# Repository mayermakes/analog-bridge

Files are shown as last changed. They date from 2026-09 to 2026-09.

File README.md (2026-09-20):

# Analog Bridge

A modular, open hardware 16-channel measurement and logic-monitoring platform built around an ATtiny3226 and four ADS1115 ADCs. The bridge exposes a line-oriented SCPI interface over Ethernet and USB serial, making it useful for automated test fixtures, digital logic observation, and lightweight data acquisition.

> **Status:** Work in progress. The hardware, firmware, and host tools are under active development.

## Features

- 16 single-ended analog inputs per device
- 3.3 V logic-level classification in the included monitor application
- Four ADS1115 converters on a shared I²C bus
- ATtiny3226-based firmware
- Ethernet connectivity through an ENC28J60
- USB-UART access at 115200 8N1
- SCPI commands for identification, channel configuration, status, and measurements
- Python web dashboards for live channel monitoring and oscilloscope-style plotting
- KiCad PCB and schematic sources
- 3D-printable enclosure plates and manufacturing files

## Repository layout

```text
analog-bridge/
├── analog-bridge-PCB/       # KiCad project, schematic, and PCB layout
├── analog-bridge/            # PlatformIO firmware and Python host tools
│   ├── src/                  # Firmware sources
│   ├── include/              # Firmware headers
│   ├── lib/                  # Project libraries
│   ├── test/                 # PlatformIO tests
│   ├── platformio.ini        # Build and upload configuration
│   ├── API_README.md         # Complete SCPI and transport reference
│   ├── analog_bridge_monitor.py
│   └── analog_bridge_oscilloscope.py
└── manufacturing/            # 3MF and SVG enclosure/manufacturing files
```

## Channel mapping

Each ADS1115 contributes four single-ended inputs:

| Logical channels | ADS1115 address | Inputs |
| --- | --- | --- |
| 0–3 | `0x48` | AIN0–AIN3 |
| 4–7 | `0x49` | AIN0–AIN3 |
| 8–11 | `0x4A` | AIN0–AIN3 |
| 12–15 | `0x4B` | AIN0–AIN3 |

The firmware uses the ADS1115 `GAIN_ONE` setting, with a nominal input range of approximately ±4.096 V. Always observe the electrical limits of the ADC and the assembled hardware.

## SCPI interface

The device accepts one command per line. Commands are case-insensitive and can be sent over either transport:

- **Ethernet:** DHCP, TCP port `5025`
- **USB serial:** `115200 8N1`

Example Ethernet session:

```bash
printf '*IDN?\n' | nc 192.168.1.42 5025
printf 'MEAS:RAW? 6\n' | nc 192.168.1.42 5025
```

Frequently used commands include:

| Command | Purpose |
| --- | --- |
| `*IDN?` | Return device identification |
| `*RST` | Restore enabled channels and 16 SPS defaults |
| `SYST:ERR?` | Read and clear the latest error |
| `CONF:CHAN<n>:RATE <sps>` | Set a channel’s sampling rate |
| `CONF:CHAN<n>:STAT ON\|OFF` | Enable or disable a channel |
| `MEAS:RAW? <n>` | Read the latest raw ADC value |
| `MEAS:RAW:ALL?` | Return all 16 channels as CSV records |

Supported rates are 8, 16, 32, 64, 128, 250, 475, and 860 SPS. For the full command reference, wiring information, response formats, and transport details, see [`analog-bridge/API_README.md`](analog-bridge/API_README.md).

> The SCPI interface has no authentication or encryption. Use Ethernet access only on a trusted network.

## Firmware development

The firmware is built with [PlatformIO](https://platformio.org/) and the Arduino framework.

### Prerequisites

- PlatformIO Core or the PlatformIO IDE extension
- An ATtiny3226 UPDI programmer
- `pymcuprog` for UPDI upload:

```bash
python3 -m pip install pymcuprog
```

### Build and upload

From the firmware directory:

```bash
cd analog-bridge
pio run
pio run -e Upload_UPDI -t upload
```

Configure the upload port and speed for your UPDI adapter according to your local setup. The default PlatformIO environment is `Upload_UPDI`.

### ADC diagnostic firmware

The repository includes a direct ADC test firmware that bypasses the normal SCPI scheduler:

```bash
pio run -e ADC_TEST -t upload
```

Open the serial port at `115200 8N1` to view probe and raw conversion output. Use this mode to isolate ADC, I²C, power, address, or wiring problems.

## Python host tools

The host applications use only the Python standard library unless USB serial discovery is needed.

### Live channel monitor

The monitor discovers up to two bridges over Ethernet or USB serial and serves a live 32-channel dashboard. Ethernet discovery scans local IPv4 `/24` networks for TCP port `5025`; USB discovery requires `pyserial`.

```bash
cd analog-bridge
python3 -m pip install pyserial  # optional, required for USB discovery
python3 analog_bridge_monitor.py
```

Open [http://127.0.0.1:8080](http://127.0.0.1:8080). By default, channels are classified as:

- `HIGH`: ≥ 2.00 V
- `LOW`: ≤ 0.80 V
- `doubt`: between the two thresholds

Customize the thresholds, serial port, or web server:

```bash
python3 analog_bridge_monitor.py \
  --serial-port /dev/ttyUSB0 \
  --high 2.2 \
  --low 0.7 \
  --port 8080
```

### Network oscilloscope

The oscilloscope discovers up to four Ethernet bridges and plots AIN0 from each ADS1115: logical channels 0, 4, 8, and 12.

```bash
python3 analog_bridge_oscilloscope.py
```

Open [http://127.0.0.1:8090](http://127.0.0.1:8090). Adjust the rolling history and polling interval with:

```bash
python3 analog_bridge_oscilloscope.py --history 60 --poll 0.1 --port 8090
```

The tools use the device’s millisecond timestamp, which is relative to device boot rather than synchronized Unix time.

## Hardware sources

The KiCad project is in [`analog-bridge-PCB/`](analog-bridge-PCB/). It includes the main PCB, project configuration, and analog-section schematic. Manufacturing and enclosure assets are in [`manufacturing/`](manufacturing/), including SVG and 3MF files.

The primary ATtiny3226 connections are:

| Function | Pin |
| --- | --- |
| I²C SCL | PB0 |
| I²C SDA | PB1 |
| UART TX | PB2 |
| UART RX | PB3 |
| ADS alert 0–3 | PB4, PB5, PC0, PC1 |
| ENC28J60 MOSI/MISO/SCK | PA1, PA2, PA3 |
| ENC28J60 CS/INT | PA4, PA6 |
| UPDI | PA0 |

## Safety and limitations

- Verify input voltage, grounding, and signal integrity before connecting external equipment.
- The analog inputs are not isolated and the SCPI network service is unauthenticated.
- Measurement rates are per-channel scheduling targets; use returned timestamps to determine the achieved rate.
- Configuration is held in RAM and returns to the default state after reset or power loss.

## Contributing

Issues and pull requests are welcome. When reporting a hardware or firmware problem, include the board revision, firmware environment, transport used, wiring, and relevant serial or SCPI output.

## License

This project is licensed under the [Open Community License v1.1 (OCL v1.1)](LICENSE), without add-on conditions.

OCL v1.1 grants non-commercial users the right to use, copy, modify, and repair the project and requires distributed derivatives to remain under OCL. Commercial business use is limited to internal use unless a separate business or repair license is obtained. See [`LICENSE`](LICENSE) for the complete terms.

Third-party components and dependencies distributed with or alongside this project remain under their respective licenses where those licenses are incompatible with OCL. The authoritative OCL text and available add-ons are maintained by the [OpenCommunityLicence project](https://github.com/OpenCommunityLicence/OpenCommunityLicence).

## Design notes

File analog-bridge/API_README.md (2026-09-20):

# Analog Bridge SCPI Interface

The analog bridge is an ATtiny3226-based 16-channel data acquisition device.
It reads four ADS1115 converters and exposes one line-oriented SCPI interface
over Ethernet and over the USB serial adapter. There is no HTTP or JSON API.

## Hardware

Four ADS1115 devices share the I2C bus. Each contributes four single-ended
inputs:

| Logical channels | ADS1115 address | Inputs |
| --- | --- | --- |
| 0-3 | `0x48` | AIN0-AIN3 |
| 4-7 | `0x49` | AIN0-AIN3 |
| 8-11 | `0x4A` | AIN0-AIN3 |
| 12-15 | `0x4B` | AIN0-AIN3 |

The ATtiny3226 wiring is:

| Function | Pin |
| --- | --- |
| I2C SCL | PB0 |
| I2C SDA | PB1 |
| UART TX | PB2 |
| UART RX | PB3 |
| ADS alert 0-3 | PB4, PB5, PC0, PC1 |
| ENC28J60 MOSI/MISO/SCK | PA1, PA2, PA3 |
| ENC28J60 CS/INT | PA4, PA6 |
| UPDI | PA0 |

## Transports

### Ethernet

The ENC28J60 obtains an address with DHCP and listens for SCPI connections on
TCP port `5025`. The startup message contains the address:

```text
SCPI ready: tcp://192.168.1.42
```

Connect with any TCP client, send one command per line, and read the response
line or lines. For example:

```bash
printf '*IDN?\n' | nc 192.168.1.42 5025
printf 'MEAS:RAW? 6\n' | nc 192.168.1.42 5025
```

The MAC address is locally administered and generated by hashing all ten bytes
of the ATtiny factory serial number. Each device therefore gets a stable MAC
without exposing the factory serial directly.

### USB serial

The ATtiny3226 firmware uses its UART; connect PB2/PB3 to a USB-UART adapter
or a board USB-UART bridge. Use `115200 8N1`, with TX/RX crossed and a shared
ground:

| ATtiny3226 | USB-UART adapter |
| --- | --- |
| PB2 / TX | RXD |
| PB3 / RX | TXD |
| GND | GND |

Send SCPI commands terminated by LF or CR/LF. Startup diagnostics are also
printed on this port, so software should ignore lines before the first command
response.

## SCPI commands

Commands are case-insensitive. Whitespace around a command is ignored. The
device processes one command per line. Query commands end in `?`; setter
commands return `OK` or the effective value.

| Command | Response / effect |
| --- | --- |
| `*IDN?` | `AnalogBridge,16-Channel Analog Bridge,ATtiny3226,1.0` |
| `*RST` | Enables all channels and restores 16 SPS; returns `OK` |
| `SYST:ERR?` | Returns `0,"No error"` or the latest error, then clears it |
| `CONF:CHAN<n>:RATE <sps>` | Sets channel `n`; returns effective rate |
| `CONF:CHAN<n>:RATE?` | Returns effective rate in SPS |
| `CONF:CHAN<n>:STAT ON` | Enables channel `n`; returns `OK` |
| `CONF:CHAN<n>:STAT OFF` | Disables channel `n`; returns `OK` |
| `CONF:CHAN<n>:STAT?` | Returns `ON` or `OFF` |
| `MEAS:RAW? <n>` | Returns the latest signed ADC code, or `NAN` before its first sample |
| `MEAS:RAW:ALL?` | Returns 16 CSV lines: `channel,enabled,rate,value,timestamp` |

`<n>` is an integer from `0` through `15`. Supported ADS1115 rates are `8`,
`16`, `32`, `64`, `128`, `250`, `475`, and `860` SPS. A requested rate is
rounded down to the greatest supported rate; values below 8 select 8 and
values above 860 select 860.

Examples:

```text
*IDN?
AnalogBridge,16-Channel Analog Bridge,ATtiny3226,1.0
CONF:CHAN6:RATE 128
128
CONF:CHAN6:STAT OFF
OK
MEAS:RAW? 6
1234
MEAS:RAW:ALL?
0,1,16,123,5812
1,1,16,NAN,NAN
...
```

Invalid commands return `ERROR`; query `SYST:ERR?` immediately afterward for
the diagnostic. The interface has no authentication or encryption, so use it
only on a trusted network.

## Measurement behavior

Values are raw signed 16-bit ADS1115 conversion results. The firmware uses
`GAIN_ONE`, whose nominal input range is approximately +/-4.096 V. Convert to
volts in host software if required, while respecting the ADS1115 electrical
limits.

The timestamp is `millis()` since boot, not Unix time. It is returned as the
fifth CSV field and is `NAN` until that channel has a valid sample. Each
ADS1115 converts one input at a time, while the four devices can convert in
parallel. The configured rate is a per-channel scheduling target; use
timestamps to measure the achieved rate. Configuration is held in RAM and
resets to all channels enabled at 16 SPS after power loss or reset.

## Minimal Python client

```python
import socket

def scpi(command, host="192.168.1.42", port=5025):
    with socket.create_connection((host, port), timeout=2) as sock:
        sock.sendall((command + "\n").encode("ascii"))
        return sock.recv(4096).decode("ascii").strip()

print(scpi("*IDN?"))
print(scpi("CONF:CHAN6:RATE 128"))
print(scpi("MEAS:RAW? 6"))
```

For continuous acquisition, keep one TCP connection open and send queries
periodically. The firmware does not emit unsolicited measurement data.

## Two-device Python monitor

`analog_bridge_monitor.py` searches the local IPv4 `/24` networks for up to two
Ethernet bridges on TCP port `5025`. It also probes USB-UART ports when
`pyserial` is installed. After discovery it continuously queries every channel
and serves a live 32-square dashboard when two devices are found:

```bash
python3 -m pip install pyserial
python3 analog_bridge_monitor.py
```

Open `http://127.0.0.1:8080`. Each square shows the device, channel, transport,
IP address or serial path, measured voltage, and the ADS timestamp. The default
3.3 V logic classification is:

For a USB-UART bridge such as `/dev/ttyUSB0`, the port can be selected
explicitly:

```bash
python3 analog_bridge_monitor.py --serial-port /dev/ttyUSB0
```

| Voltage | Display |
| --- | --- |
| `>= 2.00 V` | `HIGH` |
| `<= 0.80 V` | `LOW` |
| Between the thresholds | `doubt` in red |

Override the thresholds or web port when needed:

```bash
python3 analog_bridge_monitor.py --high 2.2 --low 0.7 --port 8080
```

The scan relies on TCP port access and validates the `*IDN?` response rather
than using broadcast. The firmware accepts one active TCP client at a time.
If the devices are on a different subnet, add that subnet to the script's
`local_networks()` function or replace discovery with known addresses.

## Direct ADC test firmware

To bypass the SCPI scheduler and test the ADS1115 hardware directly, build and
upload the `ADC_TEST` environment:

```bash
pio run -e ADC_TEST -t upload
```

`Upload_UPDI` is the default PlatformIO environment, so the PlatformIO Upload
button uploads the normal SCPI firmware. Select `ADC_TEST` only when you want
to upload the diagnostic firmware again.

Open the USB serial port at `115200 8N1`. It prints one line per input every
second:

```text
read,0x48,0,12345
read,0x48,1,12346
read,0x49,0,23456
```

The fields are `read,<ADS1115 I2C address>,<AIN channel>,<raw signed value>`.
It also prints `probe,0x48,present` or `probe,0x48,missing` at startup. A 3.3 V
input should be approximately `26000` raw counts with `GAIN_ONE`; a persistent
`0` or `ADS_MISSING` identifies an I2C, power, address, or wiring problem
independent of the normal application.

## Network oscilloscope example

`analog_bridge_oscilloscope.py` discovers up to four bridges on the local
private `/24` networks and plots AIN0 from every ADS1115 on one shared canvas.
The plotted logical channels are `0`, `4`, `8`, and `12`, corresponding to
AIN0 at addresses `0x48`, `0x49`, `0x4A`, and `0x4B`. Each device/channel can
be activated independently. It uses the `timestamp` field from
`MEAS:RAW:ALL?`, normalizes each device to its first observed timestamp, and
displays the selected traces over a shared elapsed-time axis:

```bash
python3 analog_bridge_oscilloscope.py
```

Open `http://127.0.0.1:8090`. Adjust the rolling time window and polling rate
with command-line options:

```bash
python3 analog_bridge_oscilloscope.py --history 60 --poll 0.1 --port 8090
```

The four devices do not share a hardware clock, so synchronization is relative
to each device's first observed `millis()` timestamp. The original device
timestamps remain available in the `/api/state` data returned by the example.

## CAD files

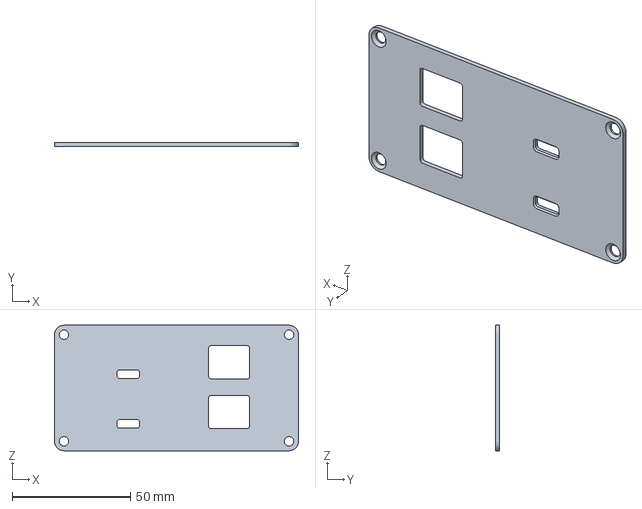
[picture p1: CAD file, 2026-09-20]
manufacturing/analog-bridge-case-plate-Host.3mf
103.0 x 1.60 x 53.0 mm

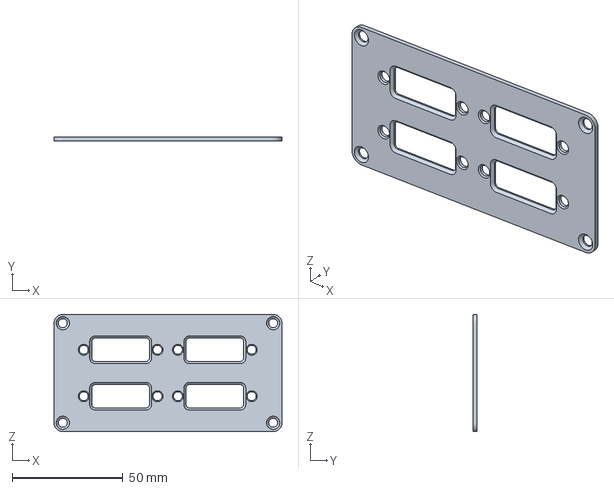
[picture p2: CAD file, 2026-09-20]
manufacturing/Plate-Input.3mf
103.0 x 1.60 x 53.0 mm

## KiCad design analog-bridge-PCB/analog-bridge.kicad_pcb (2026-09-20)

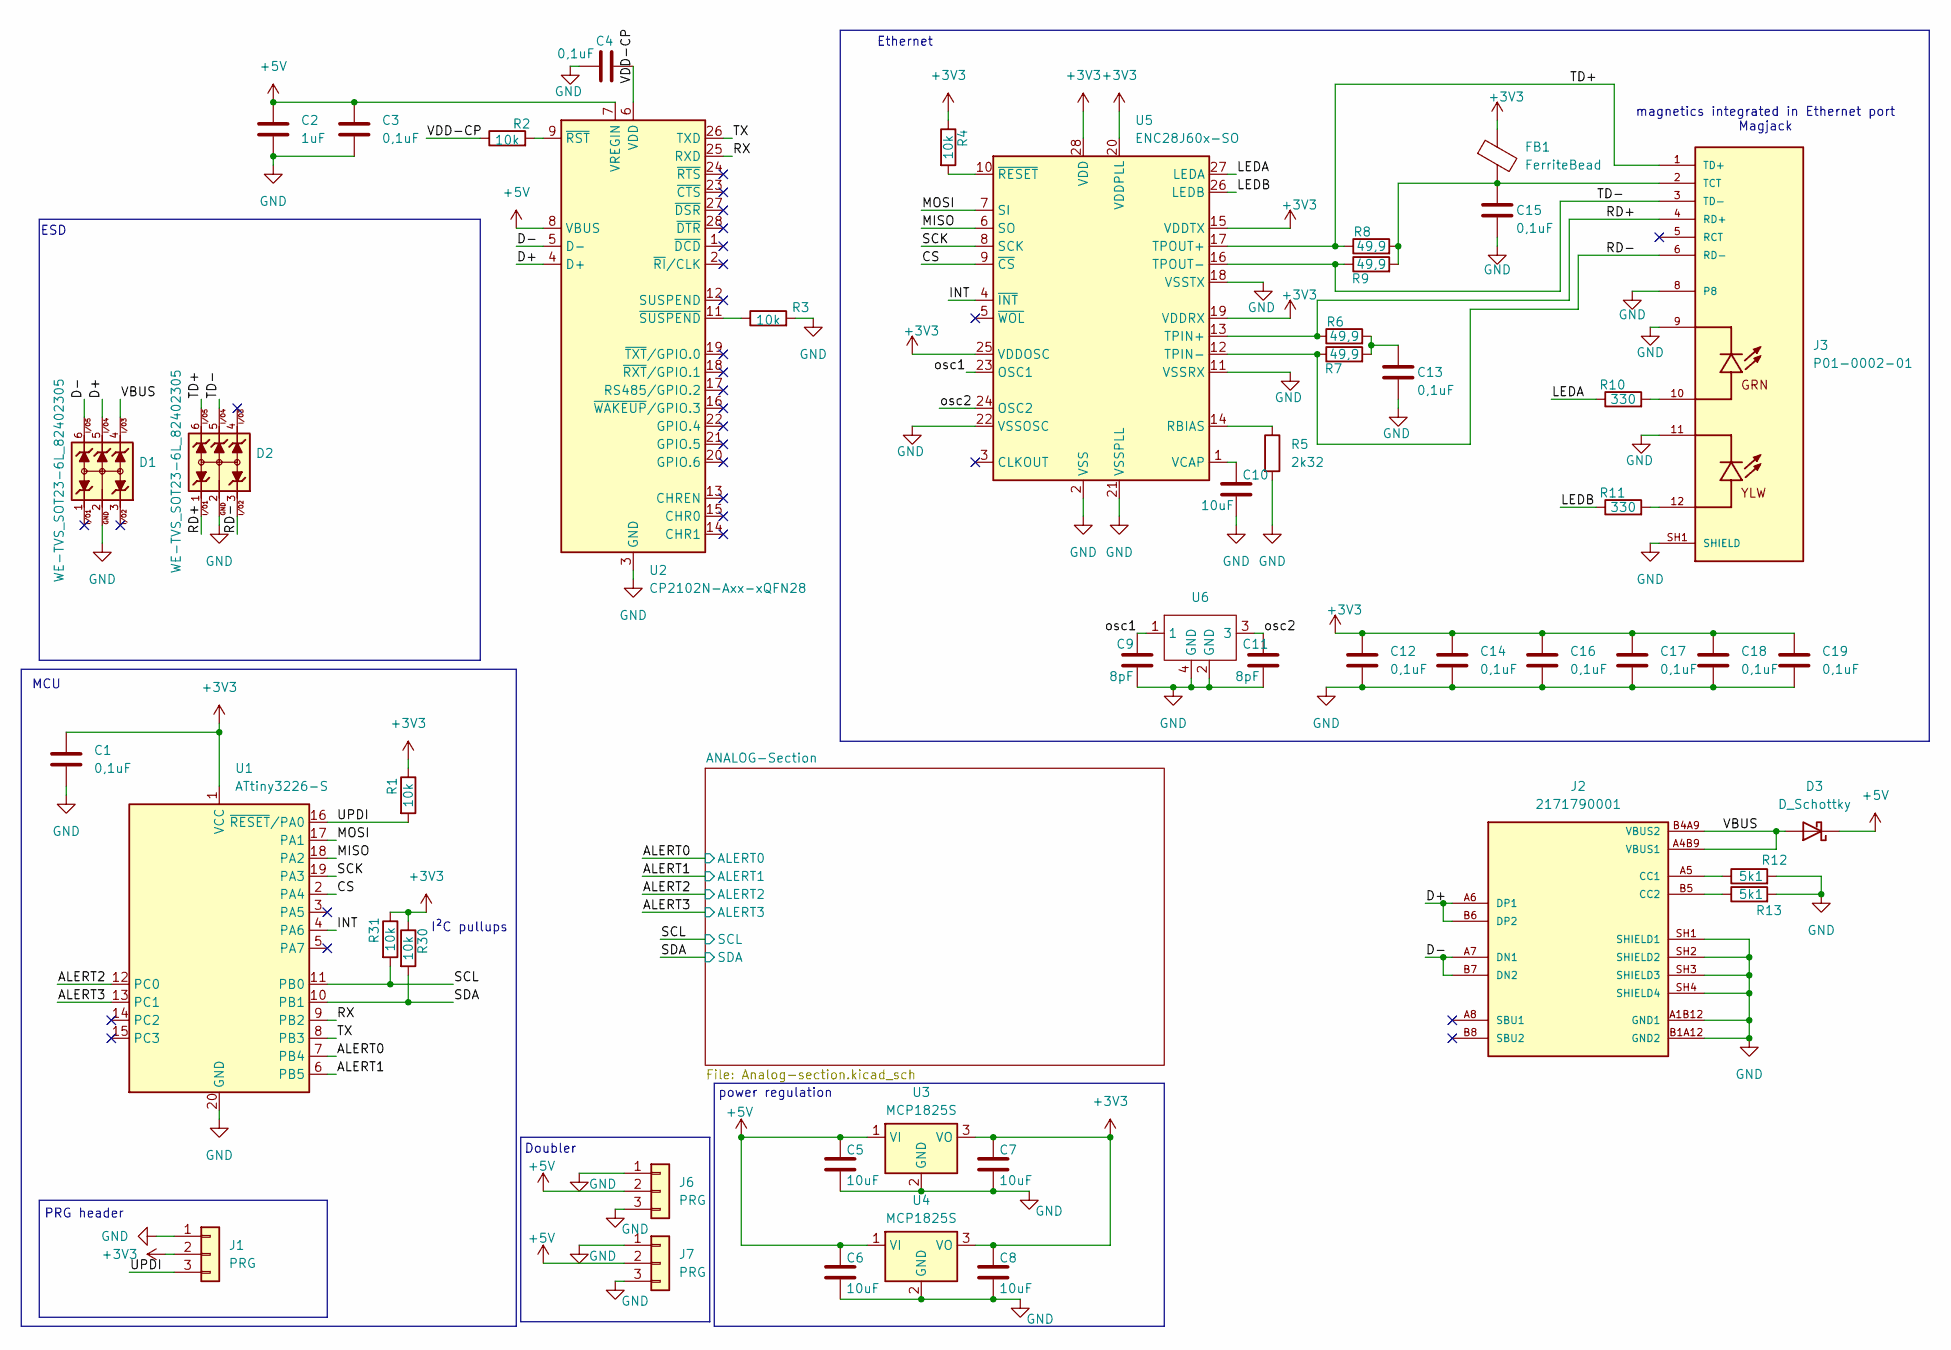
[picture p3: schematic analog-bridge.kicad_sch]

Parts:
C1, C3, C4, C12, C13, C14, C15, C16, C17, C18, C19: 0,1uF; C_0603_1608Metric
C2: 1uF; C_0603_1608Metric
C5, C6, C7, C8, C10: 10uF; C_0603_1608Metric
C9, C11: 8pF; C_0603_1608Metric
D1, D2: WE-TVS_SOT23-6L_82402305; WE-TVS_SOT23-6L
D3: D_Schottky; D_0603_1608Metric
FB1: FerriteBead; L_0603_1608Metric
J1, J6, J7: PRG; PinHeader_1x03_P2.54mm_Vertical
J2: 2171790001; MOLEX_2171790001; PARTREV A1
J3: P01-0002-01; BEL_P01-0002-01; PARTREV 1
R1, R2, R3, R4, R30, R31: 10k; R_0603_1608Metric
R5: 2k32; R_0603_1608Metric
R6, R7, R8, R9: 49,9; R_0603_1608Metric
R10, R11: 330; R_0603_1608Metric
R12, R13: 5k1; R_0603_1608Metric
U1: ATtiny3226-S; SOIC-20W_7.5x12.8mm_P1.27mm
U2: CP2102N-Axx-xQFN28; QFN-28-1EP_5x5mm_P0.5mm_EP3.35x3.35mm
U3, U4: MCP1825S; SOT-223-3_TabPin2
U5: ENC28J60x-SO; SOIC-28W_7.5x18.7mm_P1.27mm
U6: Crystal_SMD_2520-4Pin_2.5x2.0mm

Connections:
+3V3: C1.1, C7.1, C8.1, C12.1, C14.1, C16.1, C17.1, C18.1, C19.1, FB1.1, J1.2, R1.1, R4.1, R30.1, R31.1, U1.1 (VCC), U3.3 (VO), U4.3 (VO), U5.15 (VDDTX), U5.19 (VDDRX), U5.20 (VDDPLL), U5.25 (VDDOSC), U5.28 (VDD); also elsewhere on the board
+5V: C2.1, C3.1, C5.1, C6.1, D3.1 (K), J6.2, J7.2, U2.7 (VREGIN), U2.8 (VBUS), U3.1 (VI), U4.1 (VI)
/ALERT0: U1.7 (PB4); also elsewhere on the board
/ALERT1: U1.6 (PB5); also elsewhere on the board
/ALERT2: U1.12 (PC0); also elsewhere on the board
/ALERT3: U1.13 (PC1); also elsewhere on the board
/CS: U1.2 (PA4), U5.9 (~CS)
/D+: D1.5, J2.A6 (DP1), J2.B6 (DP2), U2.4 (D+)
/D-: D1.6, J2.A7 (DN1), J2.B7 (DN2), U2.5 (D-)
/INT: U1.4 (PA6), U5.4 (~INT)
/LEDA: R10.1, U5.27 (LEDA)
/LEDB: R11.1, U5.26 (LEDB)
/MISO: U1.18 (PA2), U5.6 (SO)
/MOSI: U1.17 (PA1), U5.7 (SI)
/RD+: D2.1, J3.4 (RD+), R6.1, U5.13 (TPIN+)
/RD-: D2.3, J3.6 (RD-), R7.1, U5.12 (TPIN-)
/RX: U1.9 (PB2), U2.25 (RXD)
/SCK: U1.19 (PA3), U5.8 (SCK)
/SCL: R31.2, U1.11 (PB0); also elsewhere on the board
/SDA: R30.2, U1.10 (PB1); also elsewhere on the board
/TD+: D2.6, J3.1 (TD+), R8.1, U5.17 (TPOUT+)
/TD-: D2.5, J3.3 (TD-), R9.1, U5.16 (TPOUT-)
/TX: U1.8 (PB3), U2.26 (TXD)
/UPDI: J1.3, R1.2, U1.16 (~RESET/PA0)
/VBUS: D1.4, D3.2 (A), J2.A4B9 (VBUS1), J2.B4A9 (VBUS2)
/VDD-CP: C4.2, R2.1, U2.6 (VDD)
/osc1: C9.1, U5.23 (OSC1), U6.1
/osc2: C11.1, U5.24 (OSC2), U6.3
GND: C1.2, C2.2, C3.2, C4.1, C5.2, C6.2, C7.2, C8.2, C9.2, C10.2, C11.2, C12.2, C13.2, C14.2, C15.2, C16.2, C17.2, C18.2, C19.2, D1.2, D2.2, J1.1, J2.A1B12 (GND1), J2.B1A12 (GND2), J2.SH1 (SHIELD1), J2.SH2 (SHIELD2), J2.SH3 (SHIELD3), J2.SH4 (SHIELD4), J3.8, J3.9, J3.11, J3.SH1 (SHIELD), J3.SH2 (SHIELD), J6.1, J6.3, J7.1, J7.3, R3.2, R5.2, R12.2, R13.2, U1.20 (GND), U2.3 (GND), U2.29 (GND), U3.2 (GND), U4.2 (GND), U5.2 (VSS), U5.11 (VSSRX), U5.18 (VSSTX), U5.21 (VSSPLL), U5.22 (VSSOSC), U6.2 (GND), U6.4 (GND); also elsewhere on the board
unnamed: C13.1, R6.2, R7.2
unnamed: J2.A5 (CC1), R12.1
unnamed: J2.B5 (CC2), R13.1
unnamed: J3.10, R10.2
unnamed: J3.12, R11.2
unnamed: C15.1, FB1.2, J3.2 (TCT), R8.2, R9.2
unnamed: R2.2, U2.9 (~RST)
unnamed: R3.1, U2.11 (~SUSPEND)
unnamed: R5.1, U5.14 (RBIAS)
unnamed: C10.1, U5.1 (VCAP)
unnamed: R4.2, U5.10 (~RESET)

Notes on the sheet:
power regulation
Doubler
PRG header
Ethernet
ESD
I²C pullups
MCU
magnetics integrated in Ethernet port Magjack

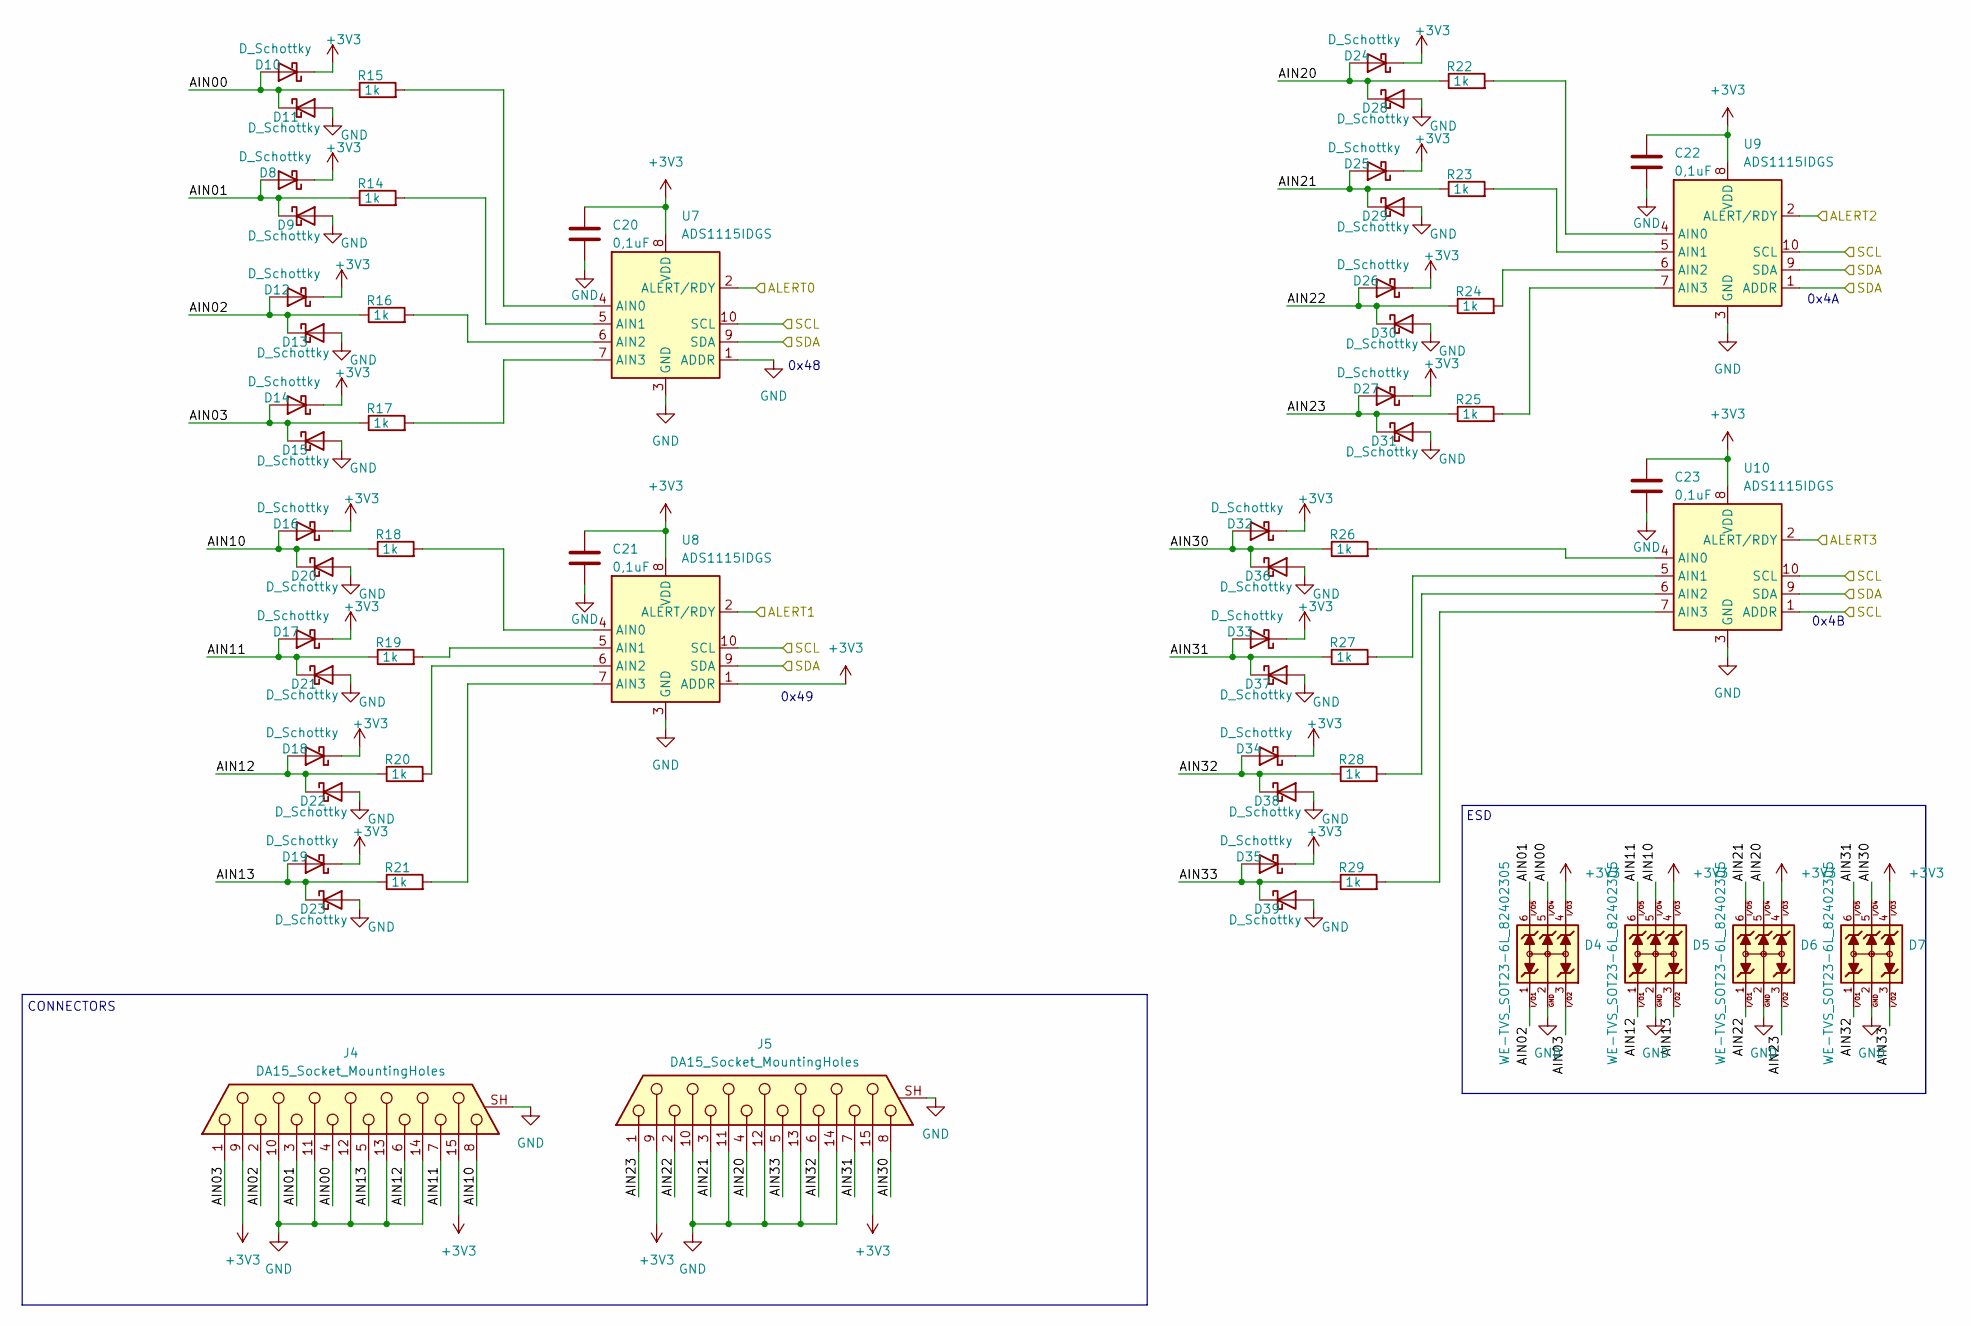
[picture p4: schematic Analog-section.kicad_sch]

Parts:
C20, C21, C22, C23: 0,1uF; C_0603_1608Metric
D4, D5, D6, D7: WE-TVS_SOT23-6L_82402305; WE-TVS_SOT23-6L
D8, D9, D10, D11, D12, D13, D14, D15, D16, D17, D18, D19, D20, D21, D22, D23, D24, D25, D26, D27, D28, D29, D30, D31, D32, D33, D34, D35, D36, D37, D38, D39: D_Schottky; D_0603_1608Metric
J4, J5: DA15_Socket_MountingHoles; DSUB-15_Socket_Horizontal_P2.77x2.84mm_EdgePinOffset7.70mm_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
R14, R15, R16, R17, R18, R19, R20, R21, R22, R23, R24, R25, R26, R27, R28, R29: 1k; R_0603_1608Metric
U7, U8, U9, U10: ADS1115IDGS; TSSOP-10_3x3mm_P0.5mm

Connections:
+3V3: C20.1, C21.1, C22.1, C23.1, D4.4, D5.4, D6.4, D7.4, D8.1 (K), D10.1 (K), D12.1 (K), D14.1 (K), D16.1 (K), D17.1 (K), D18.1 (K), D19.1 (K), D24.1 (K), D25.1 (K), D26.1 (K), D27.1 (K), D32.1 (K), D33.1 (K), D34.1 (K), D35.1 (K), J4.9, J4.15, J5.9, J5.15, U7.8 (VDD), U8.1 (ADDR), U8.8 (VDD), U9.8 (VDD), U10.8 (VDD); also elsewhere on the board
/ALERT0: U7.2 (ALERT/RDY); also elsewhere on the board
/ALERT1: U8.2 (ALERT/RDY); also elsewhere on the board
/ALERT2: U9.2 (ALERT/RDY); also elsewhere on the board
/ALERT3: U10.2 (ALERT/RDY); also elsewhere on the board
/ANALOG-Section/AIN00: D4.5, D10.2 (A), D11.1 (K), J4.4, R15.1
/ANALOG-Section/AIN01: D4.6, D8.2 (A), D9.1 (K), J4.3, R14.1
/ANALOG-Section/AIN02: D4.1, D12.2 (A), D13.1 (K), J4.2, R16.1
/ANALOG-Section/AIN03: D4.3, D14.2 (A), D15.1 (K), J4.1, R17.1
/ANALOG-Section/AIN10: D5.5, D16.2 (A), D20.1 (K), J4.8, R18.1
/ANALOG-Section/AIN11: D5.6, D17.2 (A), D21.1 (K), J4.7, R19.1
/ANALOG-Section/AIN12: D5.1, D18.2 (A), D22.1 (K), J4.6, R20.1
/ANALOG-Section/AIN13: D5.3, D19.2 (A), D23.1 (K), J4.5, R21.1
/ANALOG-Section/AIN20: D6.5, D24.2 (A), D28.1 (K), J5.4, R22.1
/ANALOG-Section/AIN21: D6.6, D25.2 (A), D29.1 (K), J5.3, R23.1
/ANALOG-Section/AIN22: D6.1, D26.2 (A), D30.1 (K), J5.2, R24.1
/ANALOG-Section/AIN23: D6.3, D27.2 (A), D31.1 (K), J5.1, R25.1
/ANALOG-Section/AIN30: D7.5, D32.2 (A), D36.1 (K), J5.8, R26.1
/ANALOG-Section/AIN31: D7.6, D33.2 (A), D37.1 (K), J5.7, R27.1
/ANALOG-Section/AIN32: D7.1, D34.2 (A), D38.1 (K), J5.6, R28.1
/ANALOG-Section/AIN33: D7.3, D35.2 (A), D39.1 (K), J5.5, R29.1
/SCL: U7.10 (SCL), U8.10 (SCL), U9.10 (SCL), U10.1 (ADDR), U10.10 (SCL); also elsewhere on the board
/SDA: U7.9 (SDA), U8.9 (SDA), U9.1 (ADDR), U9.9 (SDA), U10.9 (SDA); also elsewhere on the board
GND: C20.2, C21.2, C22.2, C23.2, D4.2, D5.2, D6.2, D7.2, D9.2 (A), D11.2 (A), D13.2 (A), D15.2 (A), D20.2 (A), D21.2 (A), D22.2 (A), D23.2 (A), D28.2 (A), D29.2 (A), D30.2 (A), D31.2 (A), D36.2 (A), D37.2 (A), D38.2 (A), D39.2 (A), J4.10, J4.11 (P111), J4.12, J4.13, J4.14, J4.SH (PAD), J5.10, J5.11 (P111), J5.12, J5.13, J5.14, J5.SH (PAD), U7.1 (ADDR), U7.3 (GND), U8.3 (GND), U9.3 (GND), U10.3 (GND); also elsewhere on the board
unnamed: R15.2, U7.4 (AIN0)
unnamed: R14.2, U7.5 (AIN1)
unnamed: R16.2, U7.6 (AIN2)
unnamed: R17.2, U7.7 (AIN3)
unnamed: R18.2, U8.4 (AIN0)
unnamed: R19.2, U8.5 (AIN1)
unnamed: R20.2, U8.6 (AIN2)
unnamed: R21.2, U8.7 (AIN3)
unnamed: R22.2, U9.4 (AIN0)
unnamed: R23.2, U9.5 (AIN1)
unnamed: R24.2, U9.6 (AIN2)
unnamed: R25.2, U9.7 (AIN3)
unnamed: R26.2, U10.4 (AIN0)
unnamed: R27.2, U10.5 (AIN1)
unnamed: R28.2, U10.6 (AIN2)
unnamed: R29.2, U10.7 (AIN3)

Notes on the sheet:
0x4A
ESD
CONNECTORS
0x48
0x49
0x4B

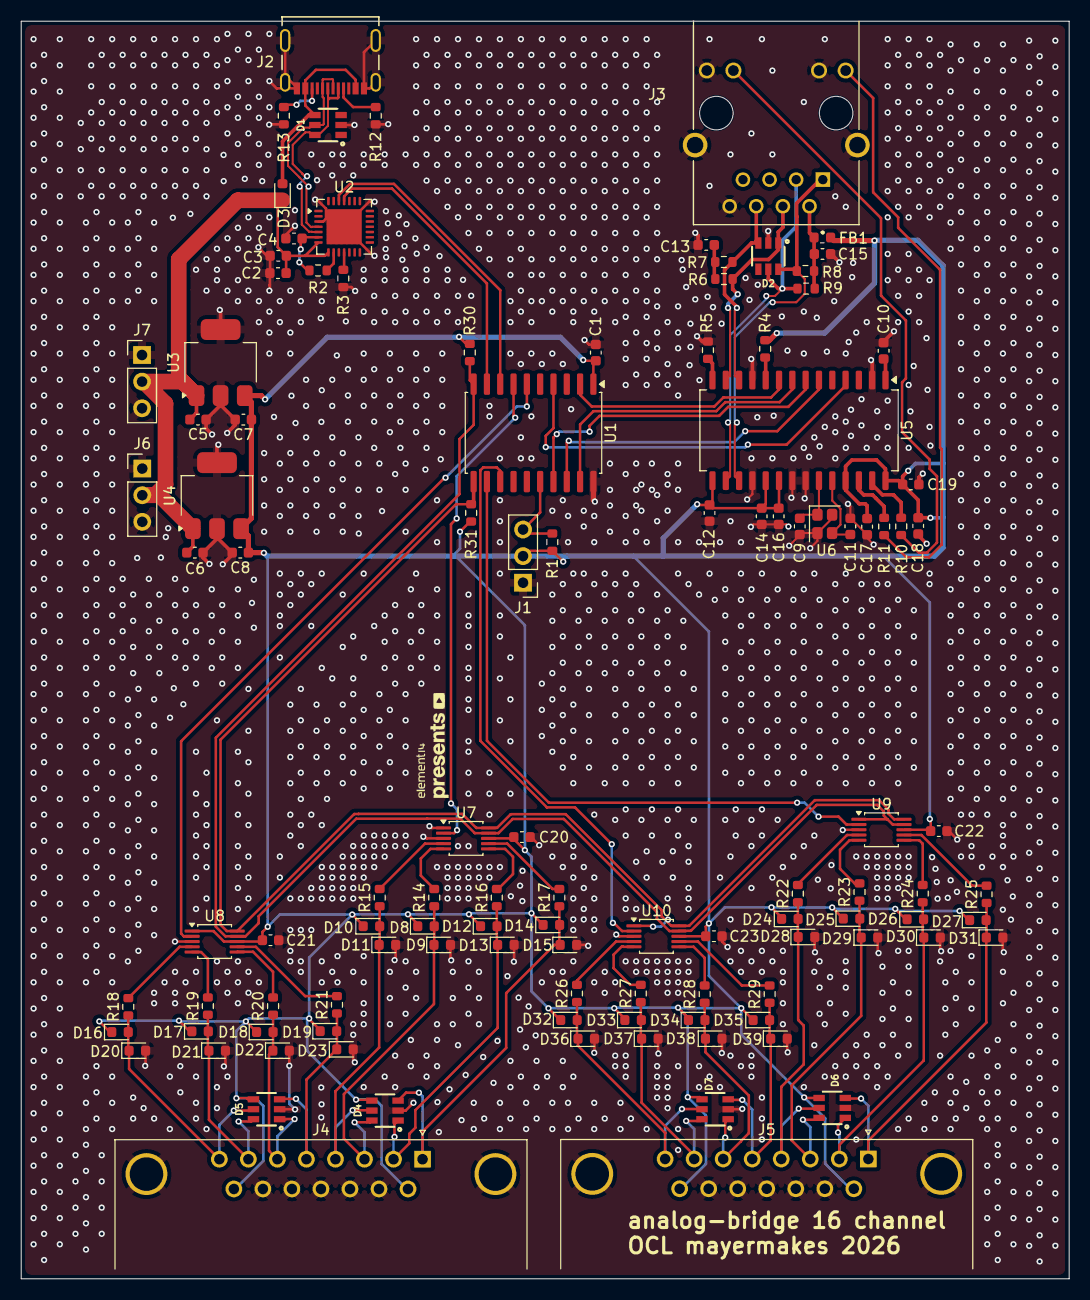
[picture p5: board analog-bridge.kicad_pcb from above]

Board: 2 copper layers, 100.0 x 120.0 mm, 112 parts (0 on the bottom side), 72 nets.

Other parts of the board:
Ref**: Val**; e14presents logo 10mm silk only v1

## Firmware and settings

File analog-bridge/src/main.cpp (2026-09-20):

#include <Adafruit_ADS1X15.h>
#include <Arduino.h>
#include <Ethernet.h>
#include <SPI.h>
#include <Wire.h>

// ATtiny3226 wiring. PA0 remains dedicated to UPDI.
constexpr uint8_t ENC28J60_CS = PIN_PA4;
constexpr uint8_t ENC28J60_INT = PIN_PA6;
constexpr uint8_t ADS_ALERT_PINS[4] = {PIN_PB4, PIN_PB5, PIN_PC0, PIN_PC1};
constexpr uint8_t ADS_ADDRESSES[4] = {0x48, 0x49, 0x4A, 0x4B};
constexpr uint16_t ADS_SINGLE_MUX[4] = {
  ADS1X15_REG_CONFIG_MUX_SINGLE_0,
  ADS1X15_REG_CONFIG_MUX_SINGLE_1,
  ADS1X15_REG_CONFIG_MUX_SINGLE_2,
  ADS1X15_REG_CONFIG_MUX_SINGLE_3
};
constexpr uint16_t SCPI_PORT = 5025;

constexpr uint8_t CHANNEL_COUNT = 16;
constexpr uint16_t DEFAULT_RATE = 16;
constexpr uint32_t DEFAULT_PERIOD_MS = 1000UL / DEFAULT_RATE;

struct ChannelConfig {
  bool enabled;
  uint16_t rate;
  uint32_t periodMs;
  uint32_t nextDue;
};

struct Sample {
  uint32_t timestampMs;
  int16_t value;
  bool valid;
};

Adafruit_ADS1115 ads[4];
ChannelConfig channelConfig[CHANNEL_COUNT];
Sample latestSamples[CHANNEL_COUNT];
EthernetServer server(SCPI_PORT);
EthernetClient ethernetScpiClient;
String serialCommand;
String ethernetCommand;
String lastScpiError = "0,\"No error\"";

volatile bool adsAlert[4] = {false, false, false, false};
int8_t activeChannel[4] = {-1, -1, -1, -1};
uint8_t nextInput[4] = {0, 0, 0, 0};
uint32_t conversionStarted[4] = {0, 0, 0, 0};

void makeMacAddress(byte mac[6]) {
  // Hash the complete factory serial so devices from the same production lot
  // cannot receive the same MAC from only the first serial bytes.
  const uint8_t serial[] = {
    SIGROW.SERNUM0, SIGROW.SERNUM1, SIGROW.SERNUM2, SIGROW.SERNUM3,
    SIGROW.SERNUM4, SIGROW.SERNUM5, SIGROW.SERNUM6, SIGROW.SERNUM7,
    SIGROW.SERNUM8, SIGROW.SERNUM9
  };
  uint64_t hash = 0xcbf29ce484222325ULL;
  for (uint8_t value : serial) {
    hash ^= value;
    hash *= 0x100000001b3ULL;
  }

  // 0x02 means locally administered unicast; the remaining bytes identify it.
  mac[0] = 0x02;
  for (uint8_t index = 0; index < 5; ++index) {
    mac[index + 1] = static_cast<byte>(hash >> (index * 8));
  }
}

void printMacAddress(const byte mac[6]) {
  for (uint8_t i = 0; i < 6; ++i) {
    if (i) Serial.print(':');
    if (mac[i] < 0x10) Serial.print('0');
    Serial.print(mac[i], HEX);
  }
}

void onAdsAlert0() { adsAlert[0] = true; }
void onAdsAlert1() { adsAlert[1] = true; }
void onAdsAlert2() { adsAlert[2] = true; }
void onAdsAlert3() { adsAlert[3] = true; }

uint16_t normalizeRate(uint16_t rate) {
  const uint16_t supported[] = {8, 16, 32, 64, 128, 250, 475, 860};
  uint16_t selected = supported[0];
  for (uint8_t i = 0; i < 8; ++i) {
    if (rate >= supported[i]) {
      selected = supported[i];
    }
  }
  return selected;
}

uint16_t adsRate(uint16_t rate) {
  switch (normalizeRate(rate)) {
    case 8: return RATE_ADS1115_8SPS;
    case 32: return RATE_ADS1115_32SPS;
    case 64: return RATE_ADS1115_64SPS;
    case 128: return RATE_ADS1115_128SPS;
    case 250: return RATE_ADS1115_250SPS;
    case 475: return RATE_ADS1115_475SPS;
    case 860: return RATE_ADS1115_860SPS;
    default: return RATE_ADS1115_16SPS;
  }
}

// Public control point for the host protocol and application code.
bool setChannelSamplingRate(uint8_t channel, uint16_t rate) {
  if (channel >= CHANNEL_COUNT || rate == 0) {
    return false;
  }
  channelConfig[channel].rate = normalizeRate(rate);
  channelConfig[channel].periodMs = 1000UL / channelConfig[channel].rate;
  channelConfig[channel].nextDue = millis();
  return true;
}

bool setChannelEnabled(uint8_t channel, bool enabled) {
  if (channel >= CHANNEL_COUNT) {
    return false;
  }
  channelConfig[channel].enabled = enabled;
  channelConfig[channel].nextDue = millis();
  return true;
}

void sendSample(uint8_t channel, int16_t value, uint32_t timestamp) {
  latestSamples[channel] = {timestamp, value, true};
}

void startDueConversions(uint32_t now) {
  for (uint8_t device = 0; device < 4; ++device) {
    if (activeChannel[device] >= 0) {
      continue;
    }
    for (uint8_t offset = 0; offset < 4; ++offset) {
      uint8_t input = (nextInput[device] + offset) % 4;
      uint8_t channel = device * 4 + input;
      if (channelConfig[channel].enabled &&
          static_cast<int32_t>(now - channelConfig[channel].nextDue) >= 0) {
        ads[device].setDataRate(adsRate(channelConfig[channel].rate));
        ads[device].startADCReading(ADS_SINGLE_MUX[input], false);
        activeChannel[device] = channel;
        nextInput[device] = (input + 1) % 4;
        conversionStarted[device] = now;
        channelConfig[channel].nextDue = now + channelConfig[channel].periodMs;
        break;
      }
    }
  }
}

void finishConversions(uint32_t now) {
  for (uint8_t device = 0; device < 4; ++device) {
    if (activeChannel[device] < 0) {
      continue;
    }
    // The alert input is wired for conversion-ready. The timeout keeps the
    // scheduler recoverable if a sensor is unplugged or its alert line fails.
    if (!ads[device].conversionComplete() && now - conversionStarted[device] < 130) {
      continue;
    }
    adsAlert[device] = false;
    int16_t value = ads[device].getLastConversionResults();
    sendSample(activeChannel[device], value, now);
    activeChannel[device] = -1;
  }
}

void setScpiError(const __FlashStringHelper *message) {
  lastScpiError = "-100,\"";
  lastScpiError += message;
  lastScpiError += '"';
}

void resetConfiguration() {
  uint32_t now = millis();
  for (uint8_t channel = 0; channel < CHANNEL_COUNT; ++channel) {
    channelConfig[channel] = {true, DEFAULT_RATE, DEFAULT_PERIOD_MS, now};
  }
}

bool parseChannel(const String &command, int &channel, int &separator) {
  if (!command.startsWith(F("CONF:CHAN"))) return false;
  separator = command.indexOf(':', 9);
  if (separator < 0) return false;
  channel = command.substring(9, separator).toInt();
  return channel >= 0 && channel < CHANNEL_COUNT;
}

void writeChannelStatus(Print &output, uint8_t channel) {
  output.print(channel);
  output.print(',');
  output.print(channelConfig[channel].enabled ? 1 : 0);
  output.print(',');
  output.print(channelConfig[channel].rate);
  output.print(',');
  if (latestSamples[channel].valid) output.print(latestSamples[channel].value);
  else output.print(F("NAN"));
  output.print(',');
  if (latestSamples[channel].valid) output.println(latestSamples[channel].timestampMs);
  else output.println(F("NAN"));
}

void processScpiCommand(String command, Print &output) {
  command.trim();
  command.toUpperCase();
  if (command.length() == 0) return;

  if (command == F("*IDN?")) {
    output.println(F("AnalogBridge,16-Channel Analog Bridge,ATtiny3226,1.0"));
    return;
  }
  if (command == F("*RST")) {
    resetConfiguration();
    output.println(F("OK"));
    return;
  }
  if (command == F("SYST:ERR?")) {
    output.println(lastScpiError);
    lastScpiError = "0,\"No error\"";
    return;
  }
  if (command == F("MEAS:RAW:ALL?")) {
    for (uint8_t channel = 0; channel < CHANNEL_COUNT; ++channel) {
      writeChannelStatus(output, channel);
    }
    return;
  }
  if (command.startsWith(F("MEAS:RAW?"))) {
    int channel = command.substring(9).toInt();
    if (channel >= 0 && channel < CHANNEL_COUNT && latestSamples[channel].valid) {
      output.println(latestSamples[channel].value);
    } else if (channel >= 0 && channel < CHANNEL_COUNT) {
      output.println(F("NAN"));
    } else {
      setScpiError(F("Invalid channel"));
      output.println(F("ERROR"));
    }
    return;
  }

  int channel;
  int separator;
  if (parseChannel(command, channel, separator)) {
    String setting = command.substring(separator);
    if (setting == F(":RATE?")) {
      output.println(channelConfig[channel].rate);
      return;
    }
    if (setting.startsWith(F(":RATE "))) {
      int rate = setting.substring(6).toInt();
      if (rate > 0 && setChannelSamplingRate(channel, rate)) {
        output.println(channelConfig[channel].rate);
      } else {
        setScpiError(F("Invalid rate"));
        output.println(F("ERROR"));
      }
      return;
    }
    if (setting == F(":STAT?")) {
      output.println(channelConfig[channel].enabled ? F("ON") : F("OFF"));
      return;
    }
    if (setting.startsWith(F(":STAT "))) {
      String state = setting.substring(6);
      if (state == F("ON") || state == F("1")) {
        setChannelEnabled(channel, true);
      } else if (state == F("OFF") || state == F("0")) {
        setChannelEnabled(channel, false);
      } else {
        setScpiError(F("Invalid state"));
        output.println(F("ERROR"));
        return;
      }
      output.println(F("OK"));
      return;
    }
  }

  setScpiError(F("Undefined header"));
  output.println(F("ERROR"));
}

template <typename T>
void readScpiInput(T &input, String &command) {
  while (input.available()) {
    char character = static_cast<char>(input.read());
    if (character == '\n' || character == '\r') {
      if (command.length()) {
        processScpiCommand(command, input);
        command = "";
      }
    } else if (command.length() < 96) {
      command += character;
    }
  }
}

void handleScpi() {
  readScpiInput(Serial, serialCommand);
  if (!ethernetScpiClient || !ethernetScpiClient.connected()) {
    ethernetScpiClient = server.available();
    ethernetCommand = "";
  }
  if (ethernetScpiClient) {
    readScpiInput(ethernetScpiClient, ethernetCommand);
  }
}

void startEthernet(const byte mac[6]) {
  while (Ethernet.begin(mac) == 0 || Ethernet.localIP() == IPAddress(0, 0, 0, 0)) {
    Serial.println(F("DHCP failed; retrying in 2 seconds"));
    delay(2000);
  }
}

void setup() {
  Serial.begin(115200);
  Wire.begin();
  Wire.setClock(400000);

  pinMode(ENC28J60_CS, OUTPUT);
  digitalWrite(ENC28J60_CS, HIGH);
  pinMode(ENC28J60_INT, INPUT_PULLUP);
  for (uint8_t i = 0; i < 4; ++i) pinMode(ADS_ALERT_PINS[i], INPUT_PULLUP);
  attachInterrupt(digitalPinToInterrupt(ADS_ALERT_PINS[0]), onAdsAlert0, FALLING);
  attachInterrupt(digitalPinToInterrupt(ADS_ALERT_PINS[1]), onAdsAlert1, FALLING);
  attachInterrupt(digitalPinToInterrupt(ADS_ALERT_PINS[2]), onAdsAlert2, FALLING);
  attachInterrupt(digitalPinToInterrupt(ADS_ALERT_PINS[3]), onAdsAlert3, FALLING);

  for (uint8_t channel = 0; channel < CHANNEL_COUNT; ++channel) {
    channelConfig[channel] = {true, DEFAULT_RATE, DEFAULT_PERIOD_MS, static_cast<uint32_t>(millis())};
    latestSamples[channel] = {0, 0, false};
  }
  for (uint8_t device = 0; device < 4; ++device) {
    if (!ads[device].begin(ADS_ADDRESSES[device])) {
      Serial.print(F("ADS1115 missing at 0x"));
      Serial.println(ADS_ADDRESSES[device], HEX);
    }
    ads[device].setGain(GAIN_ONE);
  }

  byte mac[6];
  makeMacAddress(mac);
  Serial.print(F("MAC: "));
  printMacAddress(mac);
  Serial.println();
  Ethernet.init(ENC28J60_CS);
  startEthernet(mac);
  server.begin();
  Serial.print(F("SCPI ready: tcp://"));
  Serial.println(Ethernet.localIP());
}

void loop() {
  uint32_t now = millis();
  finishConversions(now);
  startDueConversions(now);
  Ethernet.maintain();
  handleScpi();
}

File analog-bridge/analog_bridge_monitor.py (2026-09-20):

#!/usr/bin/env python3
"""Discover and monitor up to two Analog Bridge devices.

Ethernet discovery scans local IPv4 /24 networks for TCP port 5025.
USB discovery requires pyserial and probes serial ports at 115200 8N1.
The web UI is served at http://127.0.0.1:8080 by default.
"""

from __future__ import annotations

import argparse
import ipaddress
import json
import socket
import subprocess
import threading
import time
from dataclasses import dataclass, field
from concurrent.futures import ThreadPoolExecutor
from http.server import BaseHTTPRequestHandler, ThreadingHTTPServer
from typing import Optional

TCP_PORT = 5025
CHANNELS_PER_DEVICE = 16
MAX_DEVICES = 2
DEFAULT_HIGH_V = 2.0
DEFAULT_LOW_V = 0.8
DEFAULT_GAIN_V = 4.096
DEFAULT_POLL_SECONDS = 0.25


@dataclass
class Device:
    transport: str
    address: str
    label: str
    connection: object
    lock: threading.Lock = field(default_factory=threading.Lock)
    channels: list[dict] = field(default_factory=list)

    def command(self, command: str, expected_lines: int = 1) -> list[str]:
        with self.lock:
            if self.transport == "Ethernet":
                sock = self.connection
                sock.sendall((command + "\n").encode("ascii"))
                lines = read_socket_lines(sock, expected_lines)
            else:
                serial_port = self.connection
                serial_port.write((command + "\n").encode("ascii"))
                lines = []
                deadline = time.monotonic() + 2
                while len(lines) < expected_lines and time.monotonic() < deadline:
                    line = serial_port.readline().decode("ascii", errors="replace").strip()
                    if line:
                        lines.append(line)
            return lines

    def close(self) -> None:
        try:
            self.connection.close()
        except Exception:
            pass


def read_socket_lines(sock: socket.socket, count: int) -> list[str]:
    lines: list[str] = []
    buffer = b""
    deadline = time.monotonic() + 2
    while len(lines) < count and time.monotonic() < deadline:
        remaining = max(0.01, deadline - time.monotonic())
        sock.settimeout(remaining)
        try:
            chunk = sock.recv(4096)
        except socket.timeout:
            break
        if not chunk:
            break
        buffer += chunk
        while b"\n" in buffer:
            raw, buffer = buffer.split(b"\n", 1)
            line = raw.decode("ascii", errors="replace").strip()
            if line:
                lines.append(line)
                if len(lines) == count:
                    break
    return lines

def identify_ethernet(host: str) -> Optional[Device]:
    try:
        sock = socket.create_connection((host, TCP_PORT), timeout=0.25)
        sock.settimeout(2)
        sock.sendall(b"*IDN?\n")
        response = read_socket_lines(sock, 1)
        if not response or not response[0].startswith("AnalogBridge,16-Channel Analog Bridge"):
            sock.close()
            return None
        return Device("Ethernet", host, response[0], sock)
    except (OSError, ValueError):
        return None


def local_networks() -> list[ipaddress.IPv4Network]:
    networks: set[ipaddress.IPv4Network] = set()
    try:
        output = subprocess.check_output(
            ["ip", "-o", "-4", "addr", "show", "up"],
            text=True,
            stderr=subprocess.DEVNULL,
        )
        for line in output.splitlines():
            fields = line.split()
            try:
                address = fields[fields.index("inet") + 1]
                interface = ipaddress.ip_interface(address)
            except (ValueError, IndexError):
                continue
            if interface.ip.is_private:
                networks.add(ipaddress.ip_network(f"{interface.ip}/24", strict=False))
    except (OSError, subprocess.SubprocessError):
        pass
    if not networks:
        networks.add(ipaddress.ip_network("192.168.1.0/24"))
    return sorted(networks, key=str)


def discover_ethernet() -> list[Device]:
    hosts = [str(host) for network in local_networks() for host in network.hosts()]
    found: list[Device] = []
    found_lock = threading.Lock()

    def probe(host: str) -> None:
        device = identify_ethernet(host)
        if device is not None:
            with found_lock:
                if len(found) < MAX_DEVICES:
                    found.append(device)
                else:
                    device.close()

    # The bridge accepts one TCP client, so avoid flooding its listener while
    # scanning the whole subnet.
    with ThreadPoolExecutor(max_workers=16) as executor:
        list(executor.map(probe, hosts))
    return sorted(found, key=lambda device: device.address)


def discover_usb(serial_path: Optional[str] = None) -> list[Device]:
    try:
        import serial
        from serial.tools import list_ports
    except ImportError:
        return []

    found: list[Device] = []
    ports = list_ports.comports()
    if serial_path:
        ports = [port_info for port_info in ports if port_info.device == serial_path]
        if not ports:
            print(f"USB serial port not found: {serial_path}; probing available USB ports")
            ports = list_ports.comports()
    ports = [
        port_info
        for port_info in ports
        if port_info.device.startswith(("/dev/ttyUSB", "/dev/ttyACM"))
        or port_info.vid is not None
    ]
    for port_info in ports:
        try:
            serial_port = serial.Serial(
                port_info.device,
                115200,
                timeout=0.2,
                dsrdtr=False,
                rtscts=False,
            )
            # Keep CP2102 modem-control lines from holding the ATtiny in reset.
            serial_port.dtr = False
            serial_port.rts = False
            identity = ""
            time.sleep(2.0)
            for _ in range(3):
                serial_port.reset_input_buffer()
                serial_port.write(b"*IDN?\r\n")
                serial_port.flush()
                deadline = time.monotonic() + 1
                while time.monotonic() < deadline:
                    line = serial_port.readline().decode("ascii", errors="replace").strip()
                    if line.startswith("AnalogBridge,16-Channel Analog Bridge"):
                        identity = line
                        break
                if identity:
                    break
            if identity:
                found.append(Device("USB", port_info.device, identity, serial_port))
            else:
                print(f"USB port did not answer SCPI: {port_info.device} ({port_info.description})")
                serial_port.close()
        except (OSError, serial.SerialException) as error:
            print(f"Cannot open USB serial port {port_info.device}: {error}")
            continue
        if len(found) >= MAX_DEVICES:
            break
    return found
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

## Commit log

2026-09-20 Fiormware and User Software examples
    technically a multi channel oscilloscope but works only sub 1Hz.
    timestamped aquisition to corelate channels in time to the second.
2026-09-20 kicad files for one analog bridge module
    [Analog-section.kicad_sch, analog-bridge.kicad_pcb, analog-bridge.kicad_sch]
2026-09-20 End plate files for a Hammond 1455N1201BU Case
    this houses 2 modules, making it a 32 channel device
    [Plate-Input.3mf, analog-bridge-case-plate-Host.3mf]
